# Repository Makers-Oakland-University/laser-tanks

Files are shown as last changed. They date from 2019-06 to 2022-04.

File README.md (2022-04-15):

# Laser Tanks  

Laser tanks is an interactive game created by Makers @ OU. 
The game is played with 4 remote control tanks equipped with IR emitters and receivers that play laser tag. 
Work is in progress to create ESP32 based laser tanks that utilize custom PCBs that can also be modified for use in other projects. 

## Contents
This repo contains the files for PokerFace (the previous version of laser tanks). 
Files for laser tanks includes the arduino code, Tank PCB (created with KiCad), and CAD models for 3D printing.

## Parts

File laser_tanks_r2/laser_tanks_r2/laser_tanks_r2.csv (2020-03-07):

Source: | /home/tron/repos/laser-tanks/laser_tanks_r2/laser_tanks_r2/laser_tanks_r2.sch
Date: | Fri 01 Nov 2019 05:54:35 PM EDT
Tool: | Eeschema 5.1.4-e60b266~84~ubuntu18.04.1
Generator: | /usr/share/kicad/plugins/bom_csv_grouped_by_value_with_fp.py
Component Count: | 101
Ref | Qnty | Value | Cmp name | Footprint | Description | Vendor
BZ1, | 1 | Buzzer | Buzzer | digikey-footprints:Piezo_Transducer_THT_PS1240P02BT | Buzzer, polarized
C1, | 1 | 0.1u (NC) | C | Capacitor_SMD:C_0603_1608Metric_Pad1.05x0.95mm_HandSolder | Unpolarized capacitor
C2, C3, C7, C17, C20, | 5 | 10u | C | Capacitor_SMD:C_0805_2012Metric_Pad1.15x1.40mm_HandSolder | Unpolarized capacitor
C5, C4, C10, C6, C24, C23, C19, C25, C18, C28, | 10 | 0.1u | C | Capacitor_SMD:C_0603_1608Metric_Pad1.05x0.95mm_HandSolder | Unpolarized capacitor
C13, | 1 | 2.7pF | C | Capacitor_SMD:C_0603_1608Metric_Pad1.05x0.95mm_HandSolder | Unpolarized capacitor
C14, | 1 | 4.7pF | C | Capacitor_SMD:C_0603_1608Metric_Pad1.05x0.95mm_HandSolder | Unpolarized capacitor
C16, C15, | 2 | 22u | C | Capacitor_SMD:C_1206_3216Metric_Pad1.42x1.75mm_HandSolder | Unpolarized capacitor
C22, C27, C21, | 3 | 47u | C | Capacitor_SMD:CP_Elec_6.3x5.4 | Unpolarized capacitor
C26, | 1 | C | C | Capacitor_SMD:C_0805_2012Metric_Pad1.15x1.40mm_HandSolder | Unpolarized capacitor
D1, | 1 | LED | LED |  | Light emitting diode
D2, D7, | 2 | D | D |  | Diode
D3, D5, D6, | 3 | D_TVS_ALT | D_TVS_ALT |  | Bidirectional transient-voltage-suppression diode, filled shape
D4, | 1 | D_Schottky | D_Schottky |  | Schottky diode
F1, | 1 | Fuse | Fuse |  | Fuse
J1, | 1 | USB_B_Micro | USB_B_Micro |  | USB Micro Type B connector
J4, J5, J3, J15, J14, | 5 | Screw_Terminal_01x02 | Screw_Terminal_01x02 |  | Generic screw terminal, single row, 01x02, script generated (kicad-library-utils/schlib/autogen/connector/)
J6, | 1 | Conn_02x04_Odd_Even | Conn_02x04_Odd_Even |  | Generic connector, double row, 02x04, odd/even pin numbering scheme (row 1 odd numbers, row 2 even numbers), script generated (kicad-library-utils/schlib/autogen/connector/)
J7, J11, J12, J13, | 4 | Conn_01x02 | Conn_01x02 |  | Generic connector, single row, 01x02, script generated (kicad-library-utils/schlib/autogen/connector/)
J8, J9, | 2 | Conn_01x03 | Conn_01x03 |  | Generic connector, single row, 01x03, script generated (kicad-library-utils/schlib/autogen/connector/)
J10, J2, | 2 | Conn_01x04 | Conn_01x04 |  | Generic connector, single row, 01x04, script generated (kicad-library-utils/schlib/autogen/connector/)
L1, | 1 | 1.6nH | L |  | Inductor
L2, | 1 | 3.3u | L |  | Inductor
Q1, Q2, | 2 | S8050 | S8050 | Package_TO_SOT_THT:TO-92_Inline | 0.7A Ic, 20V Vce, Low Voltage High Current NPN Transistor, TO-92
Q3, | 1 | Q_PMOS_GDS | Q_PMOS_GDS |  | P-MOSFET transistor, gate/drain/source
R1, | 1 | 2k | R |  | Resistor
R3, R2, R12, R13, R29, R30, R31, R32, | 8 | 1k | R |  | Resistor
R4, | 1 | 22.1k | R |  | Resistor
R5, R7, | 2 | 47.5k | R |  | Resistor
R8, R6, | 2 | 0(NC) | R |  | Resistor
R9, R15, | 2 | 0R | R |  | Resistor
R10, R11, R18, R39, | 4 | 0 | R |  | Resistor
R14, R25, R16, R27, R26, R41, R35, R37, R36, R38, | 10 | 10k | R |  | Resistor
R17, | 1 | 100k | R |  | Resistor
R28, | 1 | 54.9k | R |  | Resistor
R33, R34, R19, | 3 | 220 | R |  | Resistor
R40, | 1 | 33.2k | R |  | Resistor
SW1, SW2, | 2 | SW_Push | SW_Push |  | Push button switch, generic, two pins
SW3, | 1 | SW_SPST | SW_SPST |  | Single Pole Single Throw (SPST) switch
U1, | 1 | AMS1117-3.3 | AMS1117-3.3 | Package_TO_SOT_SMD:SOT-223-3_TabPin2 | 1A Low Dropout regulator, positive, 3.3V fixed output, SOT-223
U2, | 1 | CP2102-GMR_NRND | CP2102-GMR_NRND | digikey-footprints:VFQFN-28-1EP_5x5mm | IC USB-TO-UART BRIDGE 28VQFN
U3, | 1 | ESP32-PICO-D4 | ESP32-PICO-D4 | ESP32-PICO-D4:PQFN50P700X700X104-49N
U6, U8, U5, | 3 | DRV8872DDA | DRV8872DDA | Package_SO:Texas_HTSOP-8-1EP_3.9x4.9mm_P1.27mm_EP2.95x4.9mm_Mask2.4x3.1mm_ThermalVias | Brushed DC Motor Driver, PWM Control, 45V, 3.6A, Current limiting, Fault Reporting, HTSOP-8
U7, | 1 | TPS565208DDCR | TPS565208DDCR
U9, U10, | 2 | DMG4822 | DMG4822

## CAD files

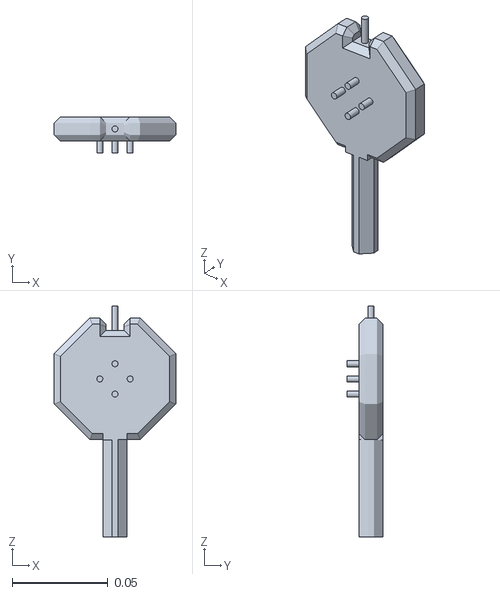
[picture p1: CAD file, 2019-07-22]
Tank Turret Assembly.stl
0.0635 x 0.0191 x 0.121

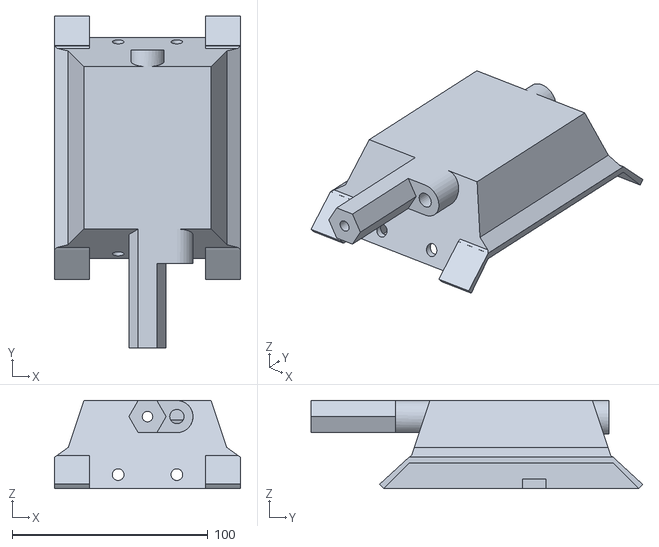
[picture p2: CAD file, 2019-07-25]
New Body/Laser Tank Shell.stl
95.0 x 169.3 x 45.0

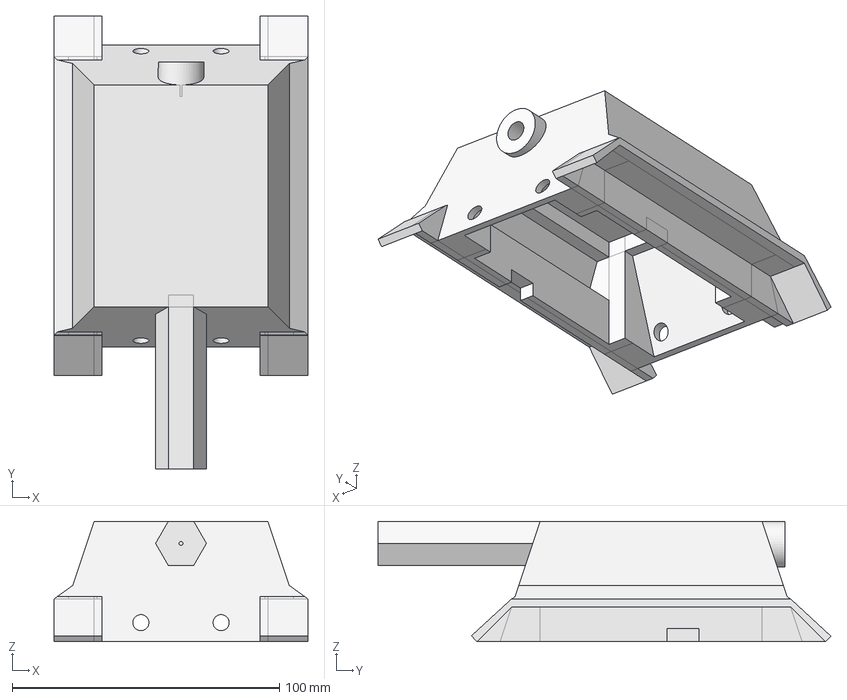
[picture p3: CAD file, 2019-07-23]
New Body/Body For Tanks (Pin).FCStd
95.0 x 169.3 x 45.0 mm

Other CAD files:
New Body/Body For Laser Tanks.FCStd
New Body/Body For Tanks (Pin).stl

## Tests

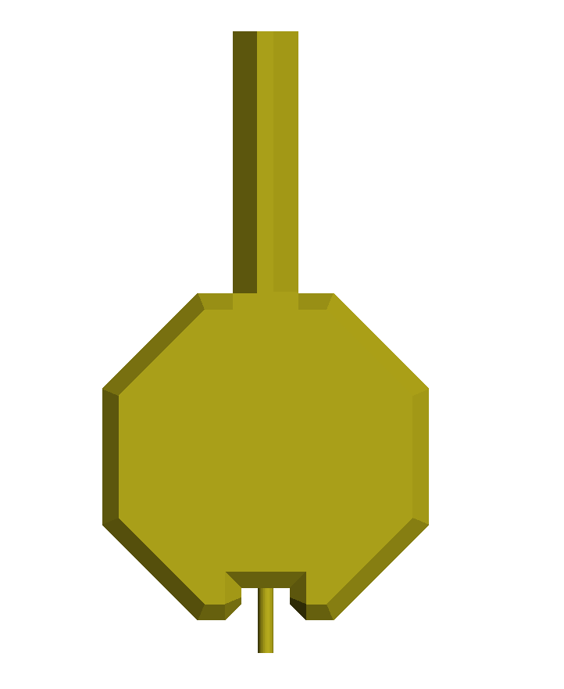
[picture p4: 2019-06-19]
Image Recognition/Test Image Group/input/top view.PNG

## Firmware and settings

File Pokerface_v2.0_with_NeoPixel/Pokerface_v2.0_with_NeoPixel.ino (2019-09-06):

#include <Adafruit_NeoPixel.h>

#include "ps2_functions.h"
#include "zumo.h"
#include "ir.h"

#define CNTL_DELAY      20
#define LASER_DELAY     50


#define PIN A1
#define NUMPIXELS 3


Adafruit_NeoPixel pixels = Adafruit_NeoPixel(NUMPIXELS, PIN, NEO_GRB + NEO_KHZ800);

void setup() {
  Serial.begin(57600);
  pinMode(PIN_LASER, OUTPUT);
  initZumo();
  initPS2();
  initIR();
  pixels.begin(); // This initializes the NeoPixel library.
}


void loop() {

  unsigned long now_ms = millis();
  static unsigned long cntl_ms, laser_ms, trig_ms, msg_ms = 0;
  static int trig = 0;
  static bool laserState = false;
  static bool hitState = false;

  // Update controller/motors
  if (now_ms -  cntl_ms >= CNTL_DELAY) {
    int left, right = 0;
    updatePS2(left, right, trig, hitState);
    if (trig == 1) {
      digitalWrite(PIN_LASER, HIGH);
      writeIR(TANK_FIRE);
    } else {
      digitalWrite(PIN_LASER, LOW);
    }
    writeMotorSpeed(left, right);
    cntl_ms = now_ms;
  }

  // Check for new data
  unsigned long msg = 0;
  msg = readIR();
  if (msg != 0 && msg == 0x1AF66ED4) {
    hitState = true;
    Serial.println(msg, HEX);
    writeMotorSpeed(400, -400);

    for (int i = 0; i < NUMPIXELS; i++) {
      pixels.setPixelColor(i, pixels.Color(255, 0, 0)); // Moderately bright green color.
      pixels.show(); // This sends the updated pixel color to the hardware.
    }

    delay(5000);
    
    for (int i = 0; i < NUMPIXELS; i++) {
      pixels.setPixelColor(i, pixels.Color(0, 255, 0)); // Moderately bright green color.
      pixels.show(); // This sends the updated pixel color to the hardware.
    }
  } else {
    hitState = false;

  }
  /*
    updatePS2(left, right);
    writeMotorSpeed(left, right);
    delay(20); */
}

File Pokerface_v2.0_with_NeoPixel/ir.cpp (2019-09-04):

#include "ir.h"
#include "Arduino.h"
#include "IRremote.h"

IRsend irsend;
IRrecv irrecv(A4);
decode_results results;

void initIR() {

  // Initialize Input
  irrecv.enableIRIn();
  Serial.println("IR Input Enabled");

}

unsigned long readIR() {
  unsigned long valResults;
  if (irrecv.decode(&results)) {
    valResults = results.value;
    irrecv.resume();
    #ifdef TEST_MODE_IR
      Serial.print("Received command: ");
      Serial.println(valResults, HEX);
  #endif
  return valResults;
  }
  else {
    return 0;
  }
  
}

// cmd MUST be 5 bits or less
void writeIR(unsigned long cmd) {
  
  irsend.sendNEC(0x1B, 8);
  irrecv.enableIRIn();
  #ifdef TEST_MODE_IR
      Serial.print("Sent command: ");
      Serial.println(0x1B, HEX);
  #endif
  
}

int checkSum(unsigned long x) {
  // Computing sanity check, currently adds all bits in number together then sees if even or odd
  int numBits = 0;
  for (int i = 0; i < 7; i++) {
    numBits += bitRead(x, i);
  }
  return (numBits % 2);
}

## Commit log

2019-06-28 Added current state from GitHub private repo, transitioning from that to BitBucket
    [lazer_tanks_r1.sch]
2019-07-03 Revised schematic to simplify circuit operation
    [lazer_tanks_r1.sch]
2019-07-03 Finalized nearly all footprints
    [lazer_tanks_r1.sch]
2019-07-20 simplified the code for the joysticks, changed switch motors to false
2019-07-20 updated/simplified joystick coding, changed flip motors to false
    [Pokerface_v2.0.ino]
2019-07-22 Added old Tank Turret STL
    [Tank Turret Assembly.stl]
2019-07-23 Created New Tank Bodies in FreeCad (STL's Included)
    [New Body for Tanks.FCStd, new body.stl]
2019-07-24 Broke v2.0 into several files internally, increasing readability and functionality
    [Pokerface_v2.0.ino, ir.cpp, ps2_functions.cpp]
2019-07-25 Created New Tank Bodies For Laser Tanks
    - Laser Tanks and Poker face tanks are also
    [Body For Laser Tanks.FCStd, Body For Tanks (Pin).FCStd, Body For Tanks (Pin).stl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]
2019-09-04 Working Laser Tag Code
2019-09-06 added neopixel version
    created new arduino sketch that supports the neoPixel (currently does not work)
    [Pokerface_v2.0_with_NeoPixel.ino, ir.cpp, ps2_functions.cpp]
2019-10-18 Making second version of board with integrated ESP32
    [laser_tanks_r2.kicad_pcb, laser_tanks_r2.sch, lazer_tanks_r1.sch]
2020-03-07 Making new real version of board (tank_board)
    [esp32_pico.sch, esp32wroom.sch, laser_tanks_r2.csv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]
2020-03-07 Renamed VCC to VBAT
    [esp32wroom.sch, tank_board.sch]
